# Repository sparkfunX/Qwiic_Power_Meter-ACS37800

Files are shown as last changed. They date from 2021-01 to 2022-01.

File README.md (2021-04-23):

SparkX Power Meter - ACS37800 (Qwiic)
===================================================

SparkX ACS37800 Power Meter (Qwiic) (SPX-17873) (https://www.sparkfun.com/products/17873)

[*SparkX Power Meter - ACS37800 (Qwiic) (SPX-17873)*](https://www.sparkfun.com/products/17873)

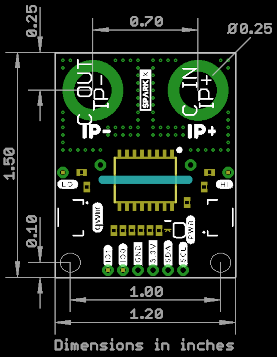
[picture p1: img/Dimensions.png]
SparkX Power Meter - ACS37800


Need a power sensor that can sense voltage up to 60VDC and current up to 30A? This is the product for you!

The Allegro MicroSystems ACS37800 power monitoring IC greatly simplifies the addition of power monitoring to many powered systems and is ideal for
heavy current applications like:
- Monitoring the power drawn by a 3D-printer
- Monitoring the power drawn from a UAV battery
- Battery charging / conditioning
- Solar / photovoltaic panel power monitoring

Allegro’s Hall-effect-based, galvanically isolated current sensing technology achieves reinforced isolation ratings in a small PCB footprint.
These features enable isolated current sensing without expensive Rogowski coils, oversized current transformers, isolated operational amplifiers,
or the power loss of shunt resistors.

The ACS37800 power monitoring IC offers key power measurement parameters that can easily be accessed through its digital interface. Dedicated and
configurable I/O pins for voltage/current zero crossing, undervoltage and overvoltage reporting, and fast overcurrent fault detection are available.
User configuration of the IC is available through on-chip EEPROM.

Important Note
-------------------
This product is not suitable for low current applications due to the +/-0.1A RMS Noise on the current channel.

Sensing less than an Amp? This is _not_ the product for you...

Safety Information
-------------------
**Although the ACS37800 power monitoring IC is capable of monitoring AC power at high line voltages, the SparkX Power Meter is designed for
Safety Extra Low Voltage (SELV) applications of up to 60VDC only. Its use in AC power systems is _not_ recommended.**

Repository Contents
-------------------
* **/Documents** - datasheets etc.
* **/Hardware** - Eagle design files (.brd, .sch)
* **/Production_Test** - production test code (.ino) - run this in the Arduino IDE
* **LICENSE.md** - license information

Documentation
--------------
* **[ACS37800 Arduino Library](https://github.com/sparkfun/SparkFun_ACS37800_Power_Monitor_Arduino_Library)** - Arduino library for the SparkFun Power Meter - ACS37800.
* **[DRAFT Hookup Guide](./HOOKUP.md)** - Basic hookup guide for the SparkX Power Meter - ACS37800.

Product Versions
----------------
* [SPX-17873](https://www.sparkfun.com/products/17873) - Original SparkX Release.

License Information
-------------------

This product is _**open source**_!

Please review the LICENSE.md file for license information.

If you have any questions or concerns on licensing, please contact technical support on our [SparkFun forums](https://forum.sparkfun.com/viewforum.php?f=123).

Distributed as-is; no warranty is given.

- Your friends at SparkFun.

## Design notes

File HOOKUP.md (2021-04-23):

# SparkX Power Meter - ACS37800 (Qwiic)

# Hook-Up Guide - DRAFT

SparkX ACS37800 Power Meter (Qwiic) (SPX-17873) (https://www.sparkfun.com/products/17873)

[*SparkX Power Meter - ACS37800 (Qwiic) (SPX-17873)*](https://www.sparkfun.com/products/17873)

Need a power sensor that can sense voltage up to 60VDC and current up to 30A? This is the product for you!

## Introduction

The Allegro MicroSystems ACS37800 power monitoring IC greatly simplifies the addition of power monitoring to many powered systems and is ideal for heavy current applications like:
- Monitoring the power drawn by a 3D-printer
- Monitoring the power drawn from a UAV battery
- Battery charging / conditioning
- Solar / photovoltaic panel power monitoring

Allegro’s Hall-effect-based, galvanically isolated current sensing technology achieves reinforced isolation ratings in a small PCB footprint. These features enable isolated current sensing without expensive Rogowski coils, oversized current transformers, isolated operational amplifiers, or the power loss of shunt resistors. The 0.85 mΩ primary conductor resistance minimises power loss and voltage drop.

The ACS37800 power monitoring IC offers key power measurement parameters that can easily be accessed through its digital interface. Dedicated and configurable I/O pins for voltage/current zero crossing, undervoltage and overvoltage reporting, and fast overcurrent fault detection are available. User configuration of the IC - including its I<sup>2</sup>C address - is available through on-chip EEPROM.

Our [Arduino library](https://github.com/sparkfun/SparkFun_ACS37800_Power_Monitor_Arduino_Library) makes it simple to add the ACS37800 into your project. We’ve also written a configuration example which you can use to examine and change all of the ACS37800’s settings through the IDE Serial Monitor or a terminal emulator.

**_Important Note:_ This product is not suitable for low current applications due to the +/-0.1A RMS Noise on the ACS37800’s current channel. Sensing less than an Amp? This is not the product for you…**

**_Safety Information:_ Although the ACS37800 power monitoring IC is capable of monitoring AC power at high line voltages, the SparkX Power Meter is designed for Safety Extra Low Voltage (SELV) applications of up to 60VDC only. Its use in AC power systems is not recommended or condoned.**

_The [SparkFun Qwiic Connect System](https://www.sparkfun.com/qwiic) is an ecosystem of I<sup>2</sup>C sensors, actuators, shields and cables that make prototyping faster and less prone to error. All Qwiic-enabled boards use a common 1mm pitch, 4-pin JST connector. This reduces the amount of required PCB space, and polarized connections mean you can’t hook it up wrong._

**_Experimental Product:_ [SparkX](https://www.sparkfun.com/sparkx) products are rapidly produced to bring you the most cutting edge technology as it becomes available. These products are tested but come with no guarantees. Live technical support is not available for SparkX products. Head on over to our [forum](https://forum.sparkfun.com/viewforum.php?f=123) for support or to ask a question.**

## High-Side Power Measurement

The Qwiic Power Meter works best in single high-side measurement applications where the ACS37800 is able to measure voltage, current and power simultaneously:
- Connect the **IP+** terminal to your voltage source
- Connect the **IP-** terminal to the load

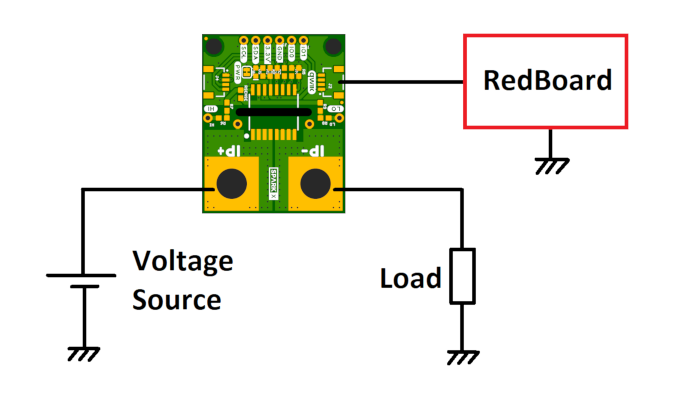
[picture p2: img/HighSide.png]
High-Side Power Measurement


In this configuration, the ACS37800 is able to measure load currents up to +/- 30 Amps. The **IP+** and **IP-** connections are electrically isolated from the rest of the circuit so, to measure voltage (and power), there needs to be a connection from the GND of the Qwiic Power Meter and RedBoard to the GND of the voltage source and load too. That connection is a low current path, only a thin wire is required, but it must be there otherwise the Qwiic Power Meter will not be able to measure voltage (and power).

Note: the RedBoard still needs to be powered in the usual way. The Qwiic Power Meter does not provide power _to_ the RedBoard.

In this example, all three Qwiic Power Meters will measure the same voltage but each will measure an individual load current and power:

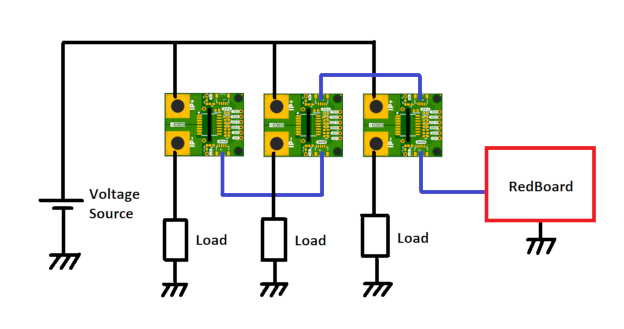
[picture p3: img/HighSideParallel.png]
High-Side Power Measurement - Parallel


The ACS37800 can be configured to use any valid I<sup>2</sup> address. The address is stored in EEPROM. Please see Example2 in the Arduino library for more details. With individual addresses, multiple Qwiic Power Meters can be daisy-chained without needing a Qwiic Mux.

In this example, all three Qwiic Power Meters will measure the same current, but different totem pole voltages (and powers):

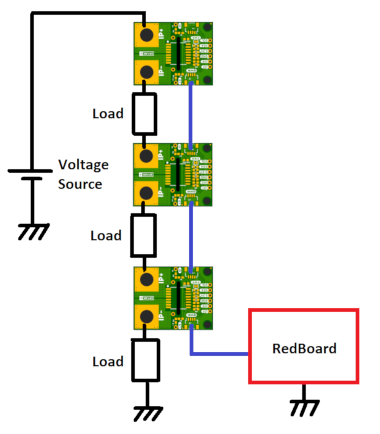
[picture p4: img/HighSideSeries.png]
High-Side Power Measurement - Series


**_Important Note:_ Be careful that the Qwiic Power Meter GND connection does not accidentally become a current path which shorts out part of the power circuit. Think very carefully before connecting a jumper wire from GND to an intermediate voltage in a multi-cell, multi-photovoltaic panel or multi-load system. Do not do this:**

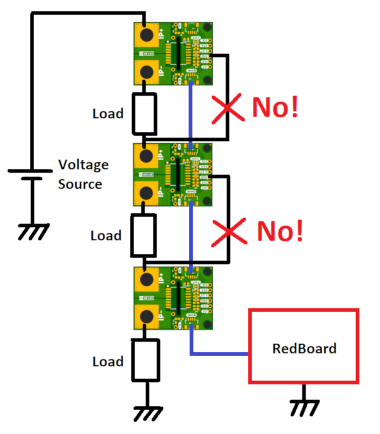
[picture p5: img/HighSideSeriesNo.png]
Do Not Do This


## Low-Side Current Measurement

The Qwiic Power Meter can be connected into the low-side of a power circuit too. However, when connected like this, it is only able to measure current, not voltage or power. (Advanced users can: cut the **IP+** split-pad jumper link on the rear of the board; and then connect the **HI** breakout pad to the high side of the load. Consult the schematic for more details.)

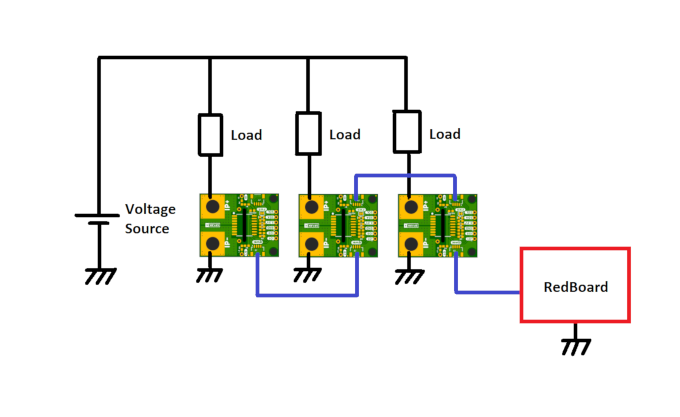
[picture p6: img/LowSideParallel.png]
Low-Side Power Measurement - Parallel


Note: the RedBoard still needs to be powered in the usual way. The Qwiic Power Meter does not provide power _to_ the RedBoard.

The ACS37800 can be configured to use any valid I<sup>2</sup> address. The address is stored in EEPROM. Please see Example2 in the Arduino library for more details. With individual addresses, multiple Qwiic Power Meters can be daisy-chained without needing a Qwiic Mux.

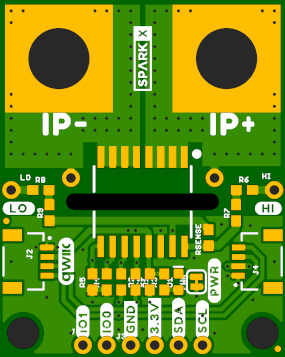
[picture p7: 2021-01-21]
img/Top.png

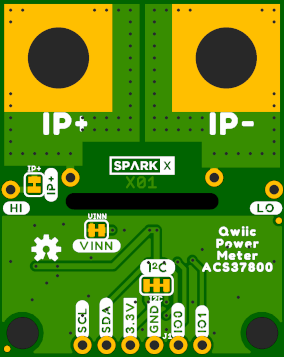
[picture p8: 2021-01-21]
img/Bottom.png

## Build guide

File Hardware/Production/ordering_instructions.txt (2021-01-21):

panel size, 138x130mm
PCB thickness, 1.6mm
number of layers, 2
soldermask color, Black
silkscreen color, White
oz copper, 2oz
finish, ENIG
stencils, top
pcs per panel, 12
min trace width, 0.4064mm / 0.0160in
min drill size, 0.3000mm / 0.0118in

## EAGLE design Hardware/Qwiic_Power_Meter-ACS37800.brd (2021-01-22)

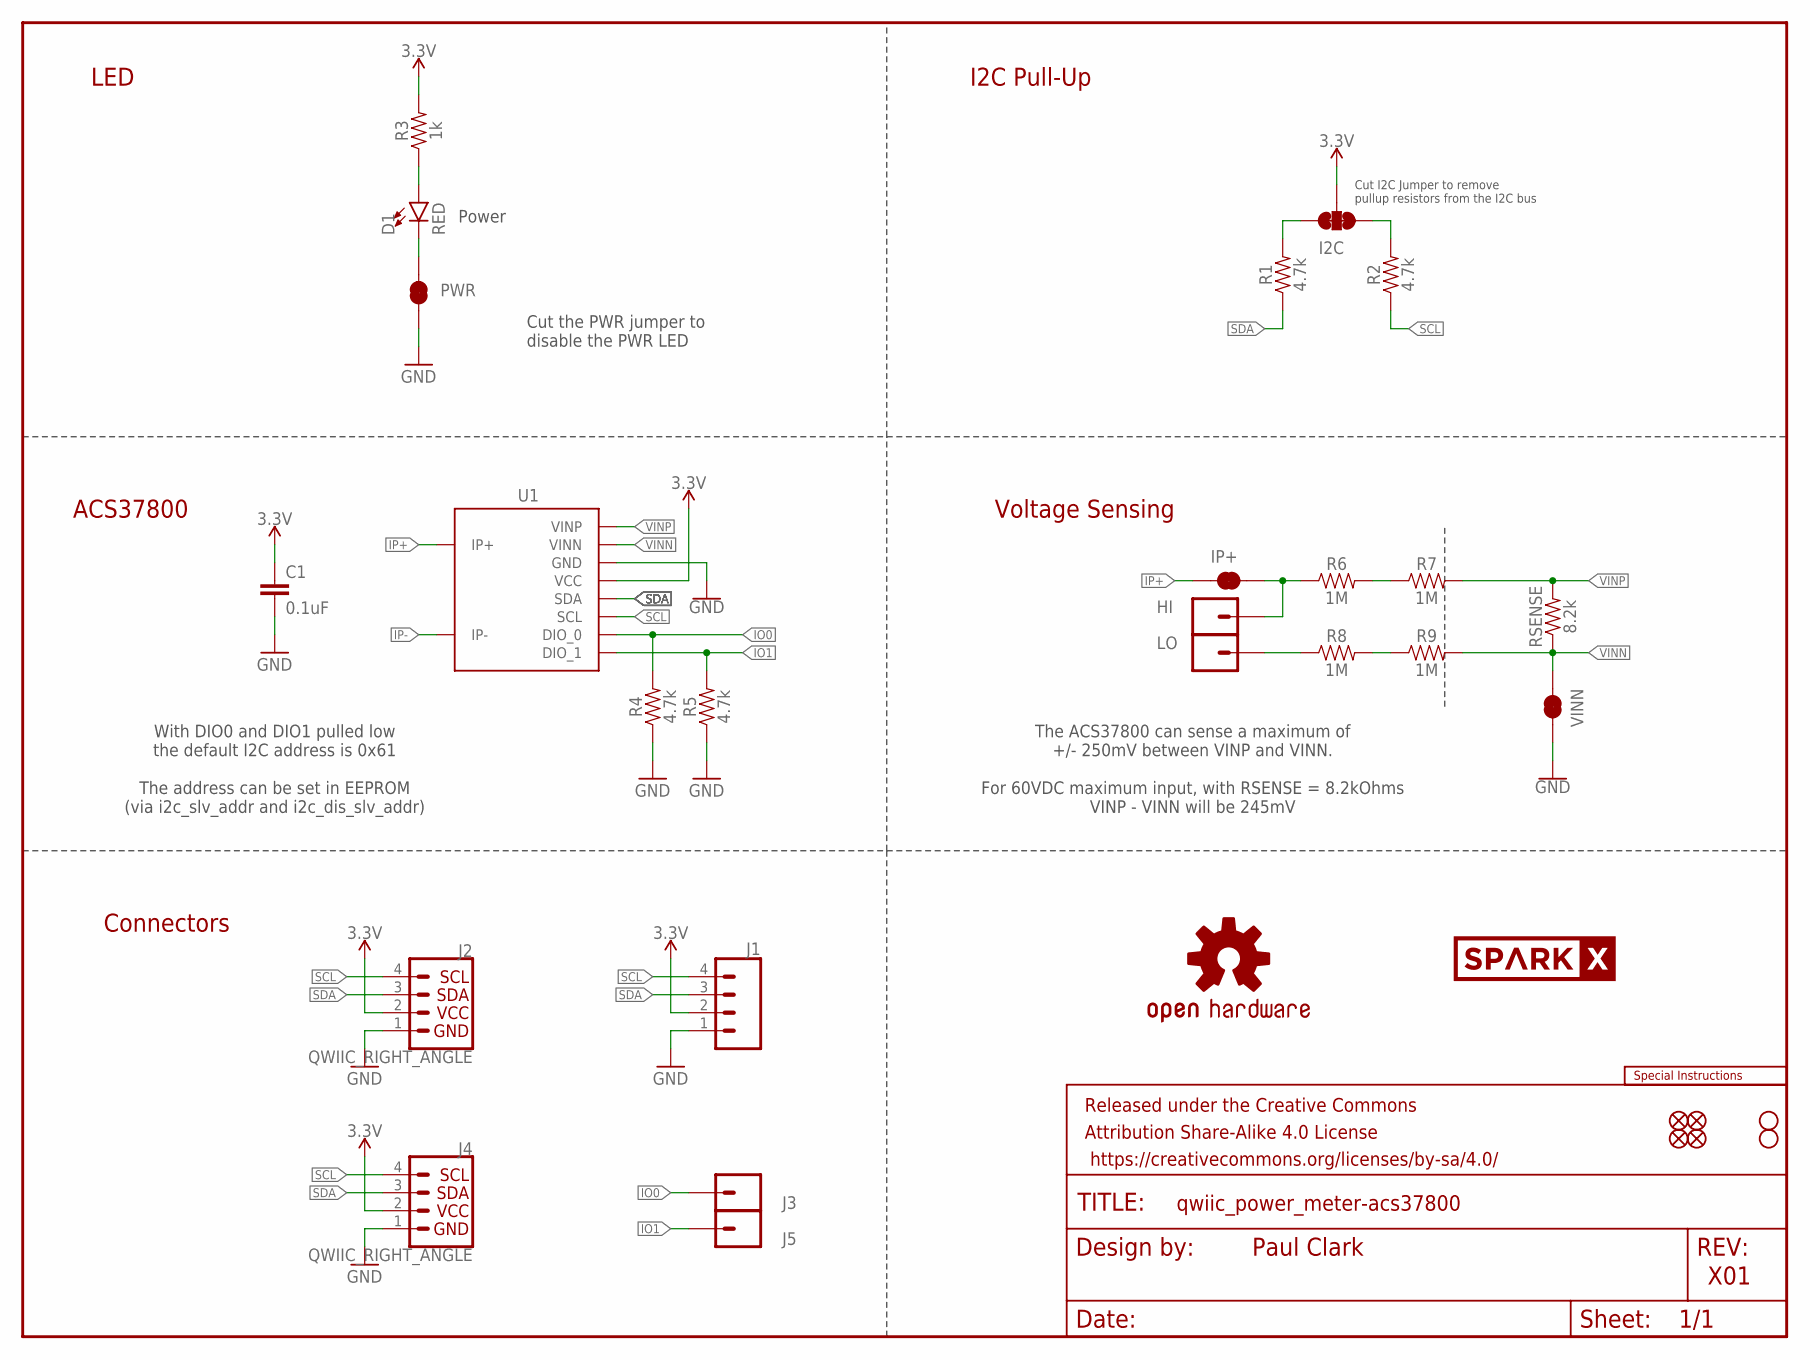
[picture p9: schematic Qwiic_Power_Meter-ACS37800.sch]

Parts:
C1: 0.1uF; 0603
D1: RED; LED-0603
FRAME1: FRAME-LETTER; CREATIVE_COMMONS
HI: CONN_01PTH_NO_SILK_YES_STOP; 1X01_NO_SILK
I2C: JUMPER-SMT_3_2-NC_TRACE_SILK; SMT-JUMPER_3_2-NC_TRACE_SILK
IP+: JUMPER-SMT_2_NC_TRACE_SILK; SMT-JUMPER_2_NC_TRACE_SILK
J1: CONN_041X04_NO_SILK; 1X04_NO_SILK
J2, J4: QWIIC_RIGHT_ANGLE; JST04_1MM_RA
J3, J5: CONN_01PTH_NO_SILK_YES_STOP; 1X01_NO_SILK
JP1, JP2, JP5, JP6: FIDUCIALUFIDUCIAL; MICRO-FIDUCIAL
JP3, JP4: STAND-OFF
LO: CONN_01PTH_NO_SILK_YES_STOP; 1X01_NO_SILK
LOGO1: SPECIAL_INSTRUCTIONS-ORDERING; ORDERING_INSTRUCTIONS
LOGO5: OSHW-LOGOS; OSHW-LOGO-S
PWR: JUMPER-SMT_2_NC_TRACE_SILK; SMT-JUMPER_2_NC_TRACE_SILK
R1, R2, R4, R5: 4.7k; 0603
R3: 1k; 0603
R6, R7, R8, R9: 1M; 0603
RSENSE: 8.2k; 0603
U1: ACS37800; ACS37800_THROUGH_HOLE
U$18: SPARKX-LOGO3; SPARKX-SMALL
VINN: JUMPER-SMT_2_NC_TRACE_SILK; SMT-JUMPER_2_NC_TRACE_SILK

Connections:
3.3V: C1.1, I2C.2, J1.2, J2.2, J4.2, R3.2, U1.13 (VCC)
GND: C1.2, J1.1, J2.1, J4.1, PWR.1, R4.1, R5.1, U1.14 (GND), VINN.2
HI: HI.1, IP+.2, R6.1
IO0: J3.1, R4.2, U1.10 (DIO_0)
IO1: J5.1, R5.2, U1.9 (DIO_1)
IP+: IP+.1, U1.1 (IP+), U1.2 (IP+), U1.3 (IP+), U1.4 (IP+), U1.CIN1 (IP+), U1.CIN2 (IP+), U1.CIN3 (IP+), U1.CIN4 (IP+), U1.CIN5 (IP+), U1.CIN6 (IP+), U1.CIN7 (IP+), U1.CIN8 (IP+), U1.CIN9 (IP+), U1.CIN10 (IP+), U1.CIN11 (IP+), U1.CIN12 (IP+), U1.CIN13 (IP+), U1.CIN14 (IP+), U1.CIN15 (IP+), U1.CIN16 (IP+), U1.CIN17 (IP+), U1.CIN18 (IP+), U1.CIN19 (IP+), U1.CIN20 (IP+), U1.CIN21 (IP+), U1.CIN22 (IP+), U1.CIN23 (IP+), U1.CIN24 (IP+), U1.CIN25 (IP+), U1.CIN26 (IP+), U1.CIN27 (IP+), U1.CIN28 (IP+), U1.CIN29 (IP+), U1.CIN30 (IP+), U1.CIN31 (IP+), U1.CIN32 (IP+), U1.CIN33 (IP+), U1.CIN34 (IP+), U1.CIN35 (IP+), U1.CIN36 (IP+), U1.C_IN (IP+), U1.C_IN_BREAKOUT (IP+)
IP-: U1.5 (IP-), U1.6 (IP-), U1.7 (IP-), U1.8 (IP-), U1.COUT1 (IP-), U1.COUT2 (IP-), U1.COUT3 (IP-), U1.COUT4 (IP-), U1.COUT5 (IP-), U1.COUT6 (IP-), U1.COUT7 (IP-), U1.COUT8 (IP-), U1.COUT9 (IP-), U1.COUT10 (IP-), U1.COUT11 (IP-), U1.COUT12 (IP-), U1.COUT13 (IP-), U1.COUT14 (IP-), U1.COUT15 (IP-), U1.COUT16 (IP-), U1.COUT17 (IP-), U1.COUT18 (IP-), U1.COUT19 (IP-), U1.COUT20 (IP-), U1.COUT21 (IP-), U1.COUT22 (IP-), U1.COUT23 (IP-), U1.COUT24 (IP-), U1.COUT25 (IP-), U1.COUT26 (IP-), U1.COUT27 (IP-), U1.COUT28 (IP-), U1.COUT29 (IP-), U1.COUT30 (IP-), U1.COUT31 (IP-), U1.COUT32 (IP-), U1.COUT33 (IP-), U1.COUT34 (IP-), U1.COUT35 (IP-), U1.COUT36 (IP-), U1.C_OUT (IP-), U1.C_OUT_BREAKOUT (IP-)
unnamed: D1.C, PWR.2
unnamed: I2C.3, R1.2
unnamed: D1.A, R3.1
unnamed: I2C.1, R2.2
unnamed: R6.2, R7.1
unnamed: R8.2, R9.1
unnamed: LO.1, R8.1
SCL: J1.4, J2.4, J4.4, R2.1, U1.11 (SCL)
SDA: J1.3, J2.3, J4.3, R1.1, U1.12 (SDA)
VINN: R9.2, RSENSE.1, U1.15 (VINN), VINN.1
VINP: R7.2, RSENSE.2, U1.16 (VINP)

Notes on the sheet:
Paul Clark
X01
Power
I2C Pull-Up
ACS37800
Connectors
Cut the PWR jumper to disable the PWR LED
Cut I2C Jumper to remove pullup resistors from the I2C bus
LED
Voltage Sensing
With DIO0 and DIO1 pulled low the default I2C address is 0x61 The address can be set in EEPROM (via i2c_slv_addr and i2c_dis_slv_addr)
The ACS37800 can sense a maximum of +/- 250mV between VINP and VINN. For 60VDC maximum input, with RSENSE = 8.2kOhms VINP - VINN will be 245mV

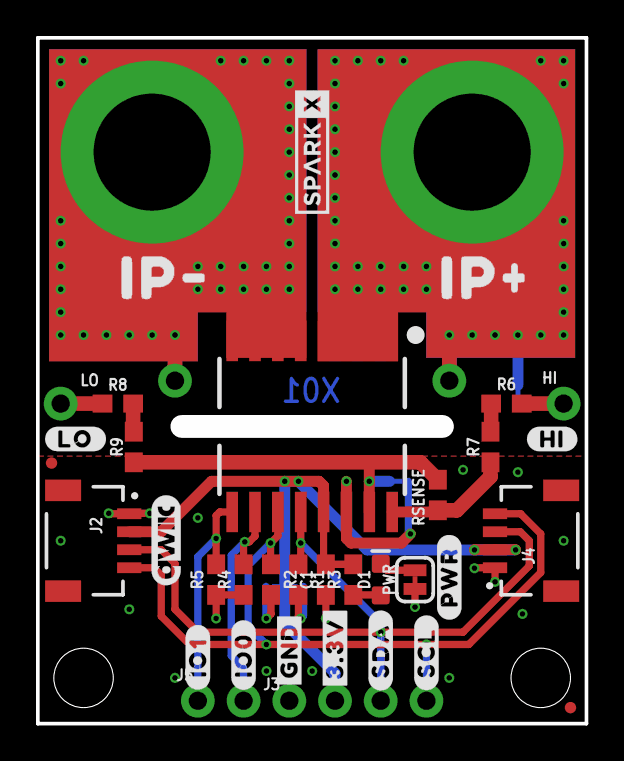
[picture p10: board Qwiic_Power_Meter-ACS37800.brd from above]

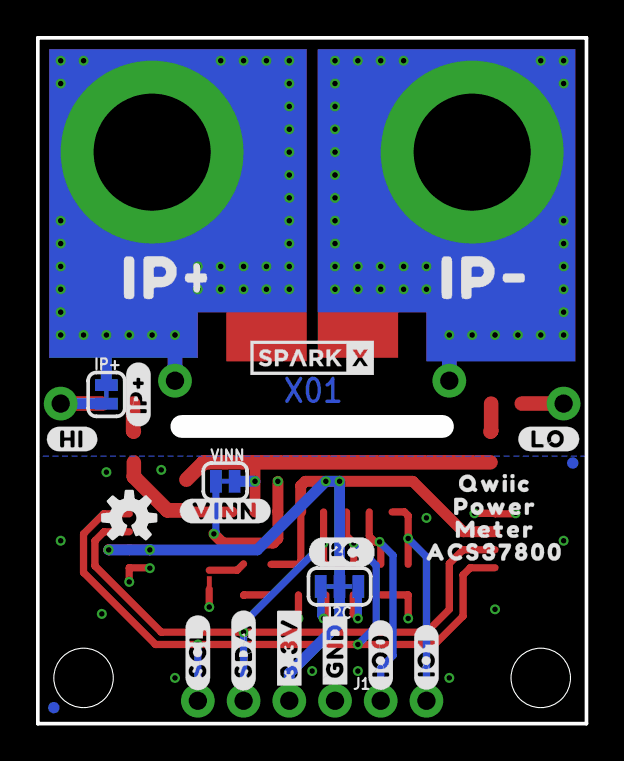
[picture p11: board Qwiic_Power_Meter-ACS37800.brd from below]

Board: 4 copper layers, 30.5 x 38.1 mm, 64 parts (25 on the bottom side), 18 nets.

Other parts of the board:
U$1, U$33: #GND#0
U$2, U$34: #3#3V#0
U$3, U$35: #SDA#0
U$4, U$36: #SCL#0
U$5, U$6: #IO0#0
U$7, U$8: #IO1#0
U$9, U$10, U$11, U$12: IP#0
U$13, U$14: #HI#0
U$15: I2C
U$16: QWIIC_5MM
U$17, U$19: #LO#0
U$20: SPARKX-LOGO3; SPARKX-SMALL
U$21: #VINN#0
U$22: #IP##0
U$23: ACS378000
U$24: METER0
U$25: POWER0
U$26: QWIIC0
U$32: #PWR#0

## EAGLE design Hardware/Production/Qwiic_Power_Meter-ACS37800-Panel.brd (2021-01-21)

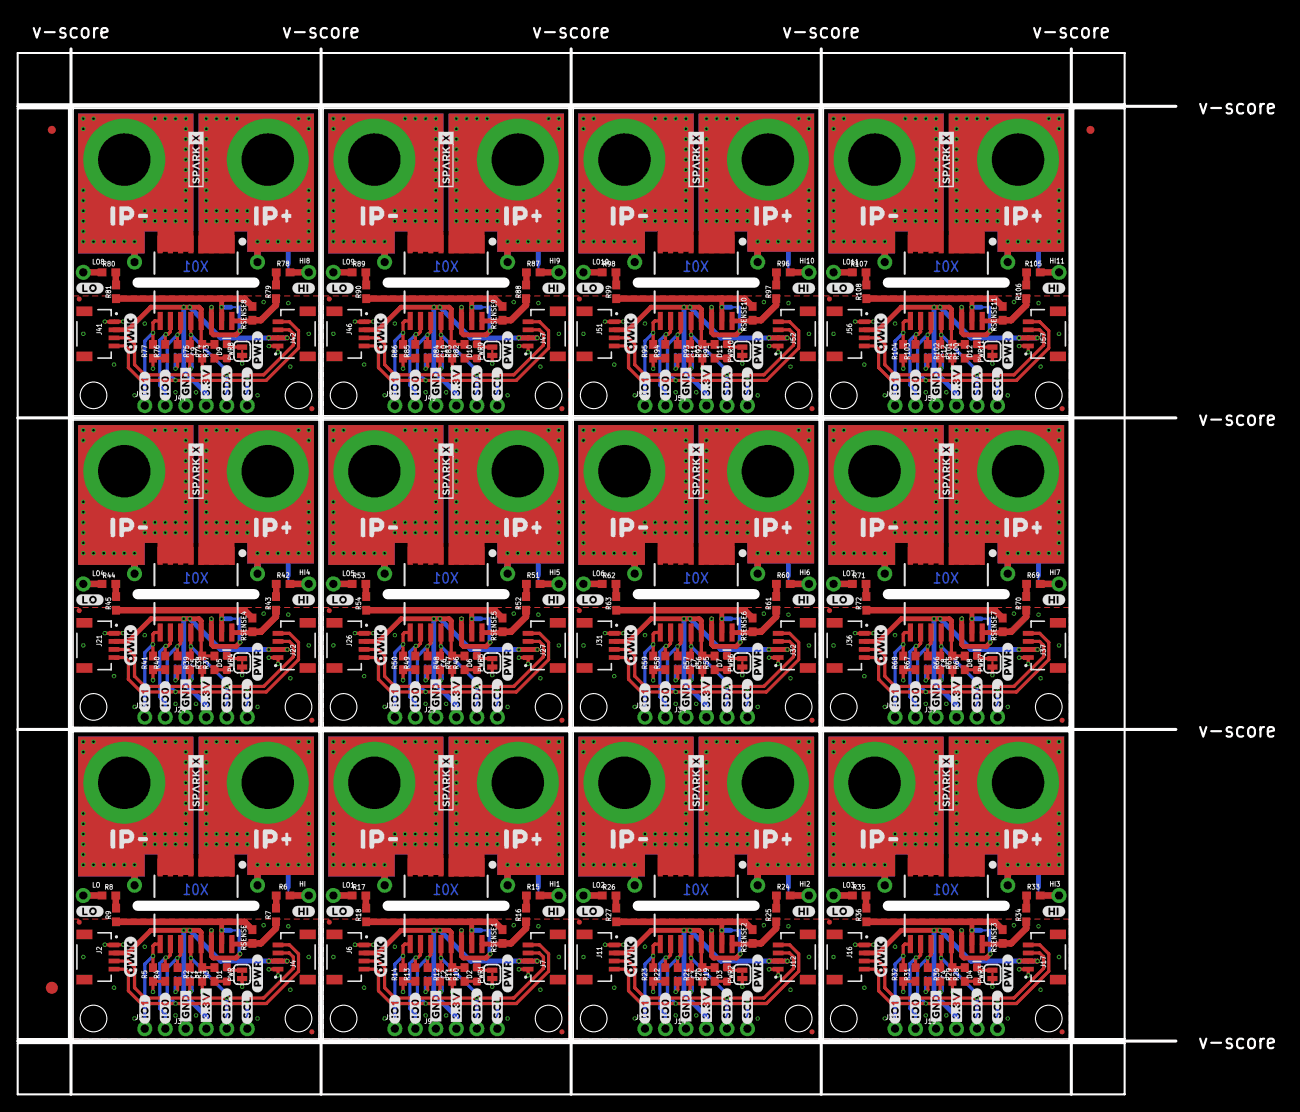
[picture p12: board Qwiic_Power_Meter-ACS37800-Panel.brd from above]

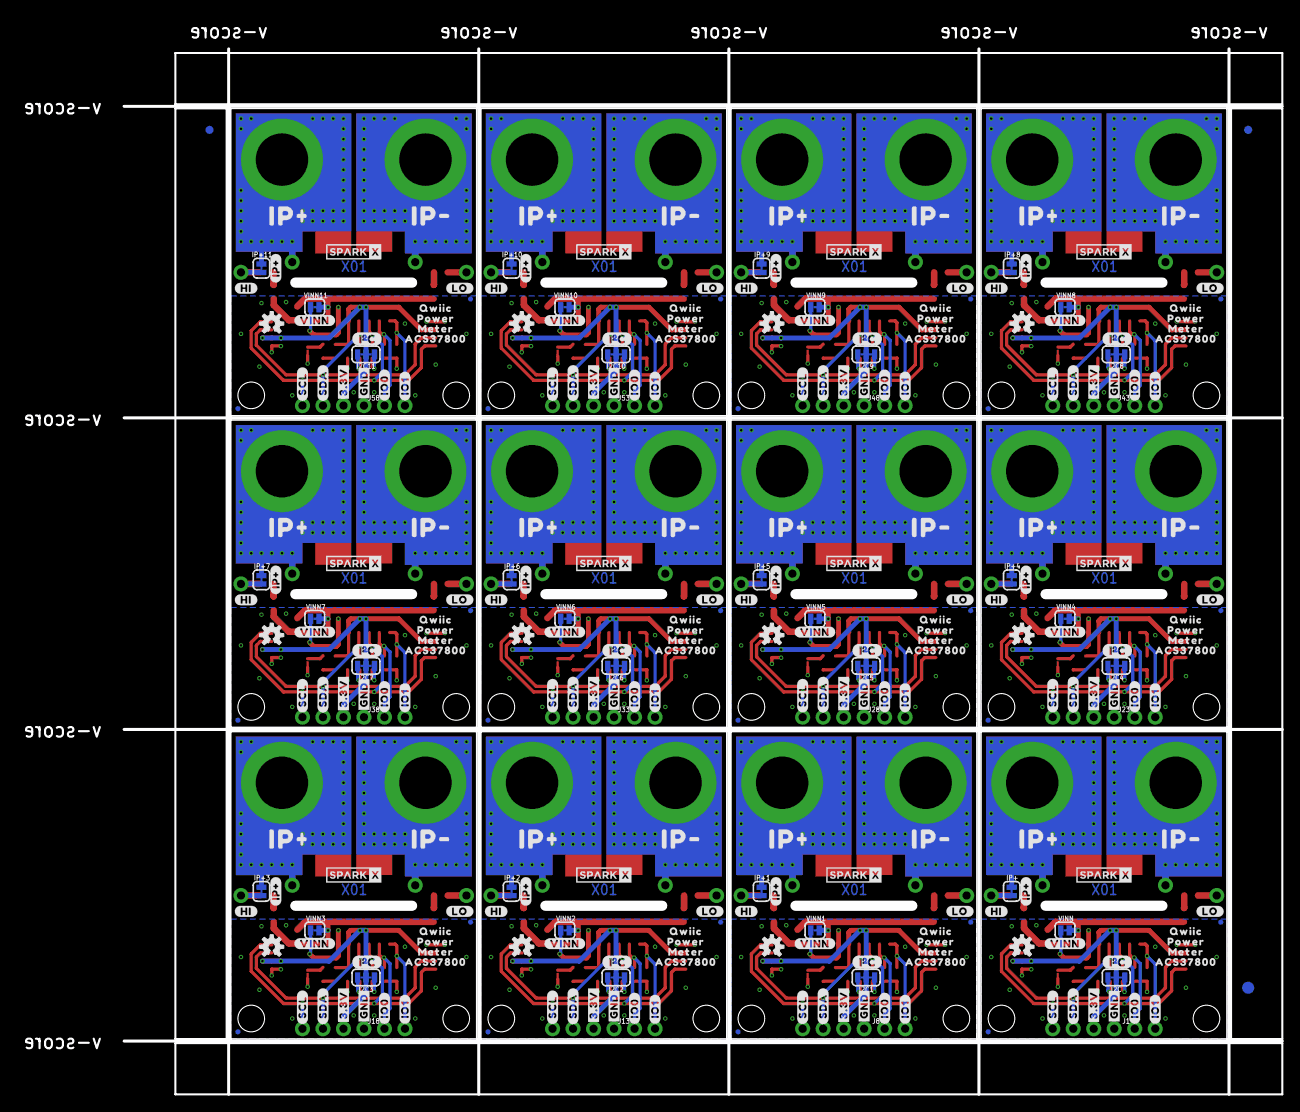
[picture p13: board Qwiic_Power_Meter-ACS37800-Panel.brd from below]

Board: 4 copper layers, 143.5 x 129.5 mm, 750 parts (303 on the bottom side), 216 nets.

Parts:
C1, C2, C3, C4, C5, C6, C7, C8, C9, C10, C11, C12: 0.1uF; 0603
D1, D2, D3, D4, D5, D6, D7, D8, D9, D10, D11, D12: RED; LED-0603
E$1, E$2, E$3, E$4: FIDUCIAL-1X2
E$5, E$6: FIDUCIAL-1.5X3
HI, HI1, HI2, HI3, HI4, HI5, HI6, HI7, HI8, HI9, HI10, HI11: 1X01_NO_SILK
I2C, I2C1, I2C2, I2C3, I2C4, I2C5, I2C6, I2C7, I2C8, I2C9, I2C10, I2C11: JUMPER-SMT_3_2-NC_TRACE_SILK; SMT-JUMPER_3_2-NC_TRACE_SILK
IP+, IP+1, IP+2, IP+3, IP+4, IP+5, IP+6, IP+7, IP+8, IP+9, IP+10, IP+11: JUMPER-SMT_2_NC_TRACE_SILK; SMT-JUMPER_2_NC_TRACE_SILK
J1, J8, J13, J18, J23, J28, J33, J38, J43, J48, J53, J58: 1X04_NO_SILK
J2, J4, J6, J7, J11, J12, J16, J17, J21, J22, J26, J27, J31, J32, J36, J37, J41, J42, J46, J47, J51, J52, J56, J57: QWIIC_RIGHT_ANGLE; JST04_1MM_RA
J3, J5, J9, J10, J14, J15, J19, J20, J24, J25, J29, J30, J34, J35, J39, J40, J44, J45, J49, J50, J54, J55, J59, J60: 1X01_NO_SILK
JP1, JP2, JP5, JP6, JP9, JP10, JP11, JP12, JP15, JP16, JP17, JP18, JP21, JP22, JP23, JP24, JP27, JP28, JP29, JP30, JP33, JP34, JP35, JP36, JP39, JP40, JP41, JP42, JP45, JP46, JP47, JP48, JP51, JP52, JP53, JP54, JP57, JP58, JP59, JP60, JP63, JP64, JP65, JP66, JP69, JP70, JP71, JP72: FIDUCIALUFIDUCIAL; MICRO-FIDUCIAL
JP3, JP4, JP7, JP8, JP13, JP14, JP19, JP20, JP25, JP26, JP31, JP32, JP37, JP38, JP43, JP44, JP49, JP50, JP55, JP56, JP61, JP62, JP67, JP68: STAND-OFF
LO, LO1, LO2, LO3, LO4, LO5, LO6, LO7, LO8, LO9, LO10, LO11: 1X01_NO_SILK
LOGO1, LOGO2, LOGO3, LOGO4, LOGO5, LOGO6, LOGO7, LOGO8, LOGO9, LOGO10, LOGO11, LOGO12: OSHW-LOGOS; OSHW-LOGO-S
PWR, PWR1, PWR2, PWR3, PWR4, PWR5, PWR6, PWR7, PWR8, PWR9, PWR10, PWR11: JUMPER-SMT_2_NC_TRACE_SILK; SMT-JUMPER_2_NC_TRACE_SILK
R1, R2, R4, R5, R11, R12, R13, R14, R20, R21, R22, R23, R29, R30, R31, R32, R38, R39, R40, R41, R47, R48, R49, R50, R56, R57, R58, R59, R65, R66, R67, R68, R74, R75, R76, R77, R83, R84, R85, R86, R92, R93, R94, R95, R101, R102, R103, R104: 4.7k; 0603
R3, R10, R19, R28, R37, R46, R55, R64, R73, R82, R91, R100: 1k; 0603
R6, R7, R8, R9, R15, R16, R17, R18, R24, R25, R26, R27, R33, R34, R35, R36, R42, R43, R44, R45, R51, R52, R53, R54, R60, R61, R62, R63, R69, R70, R71, R72, R78, R79, R80, R81, R87, R88, R89, R90, R96, R97, R98, R99, R105, R106, R107, R108: 1M; 0603
RSENSE, RSENSE1, RSENSE2, RSENSE3, RSENSE4, RSENSE5, RSENSE6, RSENSE7, RSENSE8, RSENSE9, RSENSE10, RSENSE11: 8.2k; 0603
U1, U2, U3, U4, U5, U6, U7, U8, U9, U10, U11, U12: ACS37800_THROUGH_HOLE
U$1, U$31, U$33, U$40, U$67, U$71, U$98, U$102, U$129, U$133, U$160, U$164, U$191, U$195, U$222, U$226, U$253, U$257, U$284, U$288, U$315, U$319, U$346, U$350: #GND#0
U$2, U$34, U$37, U$41, U$68, U$72, U$99, U$103, U$130, U$134, U$161, U$165, U$192, U$196, U$223, U$227, U$254, U$258, U$285, U$289, U$316, U$320, U$347, U$351: #3#3V#0
U$3, U$35, U$38, U$42, U$69, U$73, U$100, U$104, U$131, U$135, U$162, U$166, U$193, U$197, U$224, U$228, U$255, U$259, U$286, U$290, U$317, U$321, U$348, U$352: #SDA#0
U$4, U$36, U$39, U$43, U$70, U$74, U$101, U$105, U$132, U$136, U$163, U$167, U$194, U$198, U$225, U$229, U$256, U$260, U$287, U$291, U$318, U$322, U$349, U$353: #SCL#0
U$5, U$6, U$59, U$60, U$90, U$91, U$121, U$122, U$152, U$153, U$183, U$184, U$214, U$215, U$245, U$246, U$276, U$277, U$307, U$308, U$338, U$339, U$369, U$370: #IO0#0
U$7, U$8, U$61, U$62, U$92, U$93, U$123, U$124, U$154, U$155, U$185, U$186, U$216, U$217, U$247, U$248, U$278, U$279, U$309, U$310, U$340, U$341, U$371, U$372: #IO1#0
U$9, U$10, U$11, U$12, U$45, U$46, U$47, U$48, U$76, U$77, U$78, U$79, U$107, U$108, U$109, U$110, U$138, U$139, U$140, U$141, U$169, U$170, U$171, U$172, U$200, U$201, U$202, U$203, U$231, U$232, U$233, U$234, U$262, U$263, U$264, U$265, U$293, U$294, U$295, U$296, U$324, U$325, U$326, U$327, U$355, U$356, U$357, U$358: IP#0
U$13, U$14, U$49, U$50, U$80, U$81, U$111, U$112, U$142, U$143, U$173, U$174, U$204, U$205, U$235, U$236, U$266, U$267, U$297, U$298, U$328, U$329, U$359, U$360: #HI#0
U$15, U$27, U$63, U$94, U$125, U$156, U$187, U$218, U$249, U$280, U$311, U$342: I2C
U$16, U$28, U$64, U$95, U$126, U$157, U$188, U$219, U$250, U$281, U$312, U$343: QWIIC_5MM
U$17, U$19, U$51, U$52, U$82, U$83, U$113, U$114, U$144, U$145, U$175, U$176, U$206, U$207, U$237, U$238, U$268, U$269, U$299, U$300, U$330, U$331, U$361, U$362: #LO#0
U$18, U$20, U$29, U$44, U$65, U$75, U$96, U$106, U$127, U$137, U$158, U$168, U$189, U$199, U$220, U$230, U$251, U$261, U$282, U$292, U$313, U$323, U$344, U$354: SPARKX-LOGO3; SPARKX-SMALL
U$21, U$53, U$84, U$115, U$146, U$177, U$208, U$239, U$270, U$301, U$332, U$363: #VINN#0
U$22, U$54, U$85, U$116, U$147, U$178, U$209, U$240, U$271, U$302, U$333, U$364: #IP##0
U$23, U$55, U$86, U$117, U$148, U$179, U$210, U$241, U$272, U$303, U$334, U$365: ACS378000
U$24, U$56, U$87, U$118, U$149, U$180, U$211, U$242, U$273, U$304, U$335, U$366: METER0
U$25, U$57, U$88, U$119, U$150, U$181, U$212, U$243, U$274, U$305, U$336, U$367: POWER0
U$26, U$58, U$89, U$120, U$151, U$182, U$213, U$244, U$275, U$306, U$337, U$368: QWIIC0
U$30, U$32, U$66, U$97, U$128, U$159, U$190, U$221, U$252, U$283, U$314, U$345: #PWR#0
VINN, VINN1, VINN2, VINN3, VINN4, VINN5, VINN6, VINN7, VINN8, VINN9, VINN10, VINN11: JUMPER-SMT_2_NC_TRACE_SILK; SMT-JUMPER_2_NC_TRACE_SILK

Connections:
3.3V: C1.1, I2C.2, J1.2, J2.2, J4.2, R3.2, U1.13
3.3V1: C2.1, I2C1.2, J6.2, J7.2, J8.2, R10.2, U2.13
3.3V2: C3.1, I2C2.2, J11.2, J12.2, J13.2, R19.2, U3.13
3.3V3: C4.1, I2C3.2, J16.2, J17.2, J18.2, R28.2, U4.13
3.3V4: C5.1, I2C4.2, J21.2, J22.2, J23.2, R37.2, U5.13
3.3V5: C6.1, I2C5.2, J26.2, J27.2, J28.2, R46.2, U6.13
3.3V6: C7.1, I2C6.2, J31.2, J32.2, J33.2, R55.2, U7.13
3.3V7: C8.1, I2C7.2, J36.2, J37.2, J38.2, R64.2, U8.13
3.3V8: C9.1, I2C8.2, J41.2, J42.2, J43.2, R73.2, U9.13
3.3V9: C10.1, I2C9.2, J46.2, J47.2, J48.2, R82.2, U10.13
3.3V10: C11.1, I2C10.2, J51.2, J52.2, J53.2, R91.2, U11.13
3.3V11: C12.1, I2C11.2, J56.2, J57.2, J58.2, R100.2, U12.13
GND: C1.2, J1.1, J2.1, J4.1, PWR.1, R4.1, R5.1, U1.14, VINN.2
GND1: C2.2, J6.1, J7.1, J8.1, PWR1.1, R13.1, R14.1, U2.14, VINN1.2
GND2: C3.2, J11.1, J12.1, J13.1, PWR2.1, R22.1, R23.1, U3.14, VINN2.2
GND3: C4.2, J16.1, J17.1, J18.1, PWR3.1, R31.1, R32.1, U4.14, VINN3.2
GND4: C5.2, J21.1, J22.1, J23.1, PWR4.1, R40.1, R41.1, U5.14, VINN4.2
GND5: C6.2, J26.1, J27.1, J28.1, PWR5.1, R49.1, R50.1, U6.14, VINN5.2
GND6: C7.2, J31.1, J32.1, J33.1, PWR6.1, R58.1, R59.1, U7.14, VINN6.2
GND7: C8.2, J36.1, J37.1, J38.1, PWR7.1, R67.1, R68.1, U8.14, VINN7.2
GND8: C9.2, J41.1, J42.1, J43.1, PWR8.1, R76.1, R77.1, U9.14, VINN8.2
GND9: C10.2, J46.1, J47.1, J48.1, PWR9.1, R85.1, R86.1, U10.14, VINN9.2
GND10: C11.2, J51.1, J52.1, J53.1, PWR10.1, R94.1, R95.1, U11.14, VINN10.2
GND11: C12.2, J56.1, J57.1, J58.1, PWR11.1, R103.1, R104.1, U12.14, VINN11.2
HI: HI.1, IP+.2, R6.1
HI1: HI1.1, IP+1.2, R15.1
HI2: HI2.1, IP+2.2, R24.1
HI3: HI3.1, IP+3.2, R33.1
HI4: HI4.1, IP+4.2, R42.1
HI5: HI5.1, IP+5.2, R51.1
HI6: HI6.1, IP+6.2, R60.1
HI7: HI7.1, IP+7.2, R69.1
HI8: HI8.1, IP+8.2, R78.1
HI9: HI9.1, IP+9.2, R87.1
HI10: HI10.1, IP+10.2, R96.1
HI11: HI11.1, IP+11.2, R105.1
IO0: J3.1, R4.2, U1.10
IO1: J5.1, R5.2, U1.9
IO2: J9.1, R13.2, U2.10
IO3: J10.1, R14.2, U2.9
IO4: J14.1, R22.2, U3.10
IO5: J15.1, R23.2, U3.9
IO6: J19.1, R31.2, U4.10
IO7: J20.1, R32.2, U4.9
IO8: J24.1, R40.2, U5.10
IO9: J25.1, R41.2, U5.9
IO10: J29.1, R49.2, U6.10
IO11: J30.1, R50.2, U6.9
IO12: J34.1, R58.2, U7.10
IO13: J35.1, R59.2, U7.9
IO14: J39.1, R67.2, U8.10
IO15: J40.1, R68.2, U8.9
IO16: J44.1, R76.2, U9.10
IO17: J45.1, R77.2, U9.9
IO18: J49.1, R85.2, U10.10
IO19: J50.1, R86.2, U10.9
IO20: J54.1, R94.2, U11.10
IO21: J55.1, R95.2, U11.9
IO22: J59.1, R103.2, U12.10
IO23: J60.1, R104.2, U12.9
IP+: IP+.1, U1.1, U1.2, U1.3, U1.4, U1.CIN1, U1.CIN2, U1.CIN3, U1.CIN4, U1.CIN5, U1.CIN6, U1.CIN7, U1.CIN8, U1.CIN9, U1.CIN10, U1.CIN11, U1.CIN12, U1.CIN13, U1.CIN14, U1.CIN15, U1.CIN16, U1.CIN17, U1.CIN18, U1.CIN19, U1.CIN20, U1.CIN21, U1.CIN22, U1.CIN23, U1.CIN24, U1.CIN25, U1.CIN26, U1.CIN27, U1.CIN28, U1.CIN29, U1.CIN30, U1.CIN31, U1.CIN32, U1.CIN33, U1.CIN34, U1.CIN35, U1.CIN36, U1.C_IN, U1.C_IN_BREAKOUT
IP+1: IP+1.1, U2.1, U2.2, U2.3, U2.4, U2.CIN1, U2.CIN2, U2.CIN3, U2.CIN4, U2.CIN5, U2.CIN6, U2.CIN7, U2.CIN8, U2.CIN9, U2.CIN10, U2.CIN11, U2.CIN12, U2.CIN13, U2.CIN14, U2.CIN15, U2.CIN16, U2.CIN17, U2.CIN18, U2.CIN19, U2.CIN20, U2.CIN21, U2.CIN22, U2.CIN23, U2.CIN24, U2.CIN25, U2.CIN26, U2.CIN27, U2.CIN28, U2.CIN29, U2.CIN30, U2.CIN31, U2.CIN32, U2.CIN33, U2.CIN34, U2.CIN35, U2.CIN36, U2.C_IN, U2.C_IN_BREAKOUT
IP+2: IP+2.1, U3.1, U3.2, U3.3, U3.4, U3.CIN1, U3.CIN2, U3.CIN3, U3.CIN4, U3.CIN5, U3.CIN6, U3.CIN7, U3.CIN8, U3.CIN9, U3.CIN10, U3.CIN11, U3.CIN12, U3.CIN13, U3.CIN14, U3.CIN15, U3.CIN16, U3.CIN17, U3.CIN18, U3.CIN19, U3.CIN20, U3.CIN21, U3.CIN22, U3.CIN23, U3.CIN24, U3.CIN25, U3.CIN26, U3.CIN27, U3.CIN28, U3.CIN29, U3.CIN30, U3.CIN31, U3.CIN32, U3.CIN33, U3.CIN34, U3.CIN35, U3.CIN36, U3.C_IN, U3.C_IN_BREAKOUT
IP+3: IP+3.1, U4.1, U4.2, U4.3, U4.4, U4.CIN1, U4.CIN2, U4.CIN3, U4.CIN4, U4.CIN5, U4.CIN6, U4.CIN7, U4.CIN8, U4.CIN9, U4.CIN10, U4.CIN11, U4.CIN12, U4.CIN13, U4.CIN14, U4.CIN15, U4.CIN16, U4.CIN17, U4.CIN18, U4.CIN19, U4.CIN20, U4.CIN21, U4.CIN22, U4.CIN23, U4.CIN24, U4.CIN25, U4.CIN26, U4.CIN27, U4.CIN28, U4.CIN29, U4.CIN30, U4.CIN31, U4.CIN32, U4.CIN33, U4.CIN34, U4.CIN35, U4.CIN36, U4.C_IN, U4.C_IN_BREAKOUT
IP+4: IP+4.1, U5.1, U5.2, U5.3, U5.4, U5.CIN1, U5.CIN2, U5.CIN3, U5.CIN4, U5.CIN5, U5.CIN6, U5.CIN7, U5.CIN8, U5.CIN9, U5.CIN10, U5.CIN11, U5.CIN12, U5.CIN13, U5.CIN14, U5.CIN15, U5.CIN16, U5.CIN17, U5.CIN18, U5.CIN19, U5.CIN20, U5.CIN21, U5.CIN22, U5.CIN23, U5.CIN24, U5.CIN25, U5.CIN26, U5.CIN27, U5.CIN28, U5.CIN29, U5.CIN30, U5.CIN31, U5.CIN32, U5.CIN33, U5.CIN34, U5.CIN35, U5.CIN36, U5.C_IN, U5.C_IN_BREAKOUT
IP+5: IP+5.1, U6.1, U6.2, U6.3, U6.4, U6.CIN1, U6.CIN2, U6.CIN3, U6.CIN4, U6.CIN5, U6.CIN6, U6.CIN7, U6.CIN8, U6.CIN9, U6.CIN10, U6.CIN11, U6.CIN12, U6.CIN13, U6.CIN14, U6.CIN15, U6.CIN16, U6.CIN17, U6.CIN18, U6.CIN19, U6.CIN20, U6.CIN21, U6.CIN22, U6.CIN23, U6.CIN24, U6.CIN25, U6.CIN26, U6.CIN27, U6.CIN28, U6.CIN29, U6.CIN30, U6.CIN31, U6.CIN32, U6.CIN33, U6.CIN34, U6.CIN35, U6.CIN36, U6.C_IN, U6.C_IN_BREAKOUT
IP+6: IP+6.1, U7.1, U7.2, U7.3, U7.4, U7.CIN1, U7.CIN2, U7.CIN3, U7.CIN4, U7.CIN5, U7.CIN6, U7.CIN7, U7.CIN8, U7.CIN9, U7.CIN10, U7.CIN11, U7.CIN12, U7.CIN13, U7.CIN14, U7.CIN15, U7.CIN16, U7.CIN17, U7.CIN18, U7.CIN19, U7.CIN20, U7.CIN21, U7.CIN22, U7.CIN23, U7.CIN24, U7.CIN25, U7.CIN26, U7.CIN27, U7.CIN28, U7.CIN29, U7.CIN30, U7.CIN31, U7.CIN32, U7.CIN33, U7.CIN34, U7.CIN35, U7.CIN36, U7.C_IN, U7.C_IN_BREAKOUT
IP+7: IP+7.1, U8.1, U8.2, U8.3, U8.4, U8.CIN1, U8.CIN2, U8.CIN3, U8.CIN4, U8.CIN5, U8.CIN6, U8.CIN7, U8.CIN8, U8.CIN9, U8.CIN10, U8.CIN11, U8.CIN12, U8.CIN13, U8.CIN14, U8.CIN15, U8.CIN16, U8.CIN17, U8.CIN18, U8.CIN19, U8.CIN20, U8.CIN21, U8.CIN22, U8.CIN23, U8.CIN24, U8.CIN25, U8.CIN26, U8.CIN27, U8.CIN28, U8.CIN29, U8.CIN30, U8.CIN31, U8.CIN32, U8.CIN33, U8.CIN34, U8.CIN35, U8.CIN36, U8.C_IN, U8.C_IN_BREAKOUT
IP+8: IP+8.1, U9.1, U9.2, U9.3, U9.4, U9.CIN1, U9.CIN2, U9.CIN3, U9.CIN4, U9.CIN5, U9.CIN6, U9.CIN7, U9.CIN8, U9.CIN9, U9.CIN10, U9.CIN11, U9.CIN12, U9.CIN13, U9.CIN14, U9.CIN15, U9.CIN16, U9.CIN17, U9.CIN18, U9.CIN19, U9.CIN20, U9.CIN21, U9.CIN22, U9.CIN23, U9.CIN24, U9.CIN25, U9.CIN26, U9.CIN27, U9.CIN28, U9.CIN29, U9.CIN30, U9.CIN31, U9.CIN32, U9.CIN33, U9.CIN34, U9.CIN35, U9.CIN36, U9.C_IN, U9.C_IN_BREAKOUT
IP+9: IP+9.1, U10.1, U10.2, U10.3, U10.4, U10.CIN1, U10.CIN2, U10.CIN3, U10.CIN4, U10.CIN5, U10.CIN6, U10.CIN7, U10.CIN8, U10.CIN9, U10.CIN10, U10.CIN11, U10.CIN12, U10.CIN13, U10.CIN14, U10.CIN15, U10.CIN16, U10.CIN17, U10.CIN18, U10.CIN19, U10.CIN20, U10.CIN21, U10.CIN22, U10.CIN23, U10.CIN24, U10.CIN25, U10.CIN26, U10.CIN27, U10.CIN28, U10.CIN29, U10.CIN30, U10.CIN31, U10.CIN32, U10.CIN33, U10.CIN34, U10.CIN35, U10.CIN36, U10.C_IN, U10.C_IN_BREAKOUT
IP+10: IP+10.1, U11.1, U11.2, U11.3, U11.4, U11.CIN1, U11.CIN2, U11.CIN3, U11.CIN4, U11.CIN5, U11.CIN6, U11.CIN7, U11.CIN8, U11.CIN9, U11.CIN10, U11.CIN11, U11.CIN12, U11.CIN13, U11.CIN14, U11.CIN15, U11.CIN16, U11.CIN17, U11.CIN18, U11.CIN19, U11.CIN20, U11.CIN21, U11.CIN22, U11.CIN23, U11.CIN24, U11.CIN25, U11.CIN26, U11.CIN27, U11.CIN28, U11.CIN29, U11.CIN30, U11.CIN31, U11.CIN32, U11.CIN33, U11.CIN34, U11.CIN35, U11.CIN36, U11.C_IN, U11.C_IN_BREAKOUT
IP+11: IP+11.1, U12.1, U12.2, U12.3, U12.4, U12.CIN1, U12.CIN2, U12.CIN3, U12.CIN4, U12.CIN5, U12.CIN6, U12.CIN7, U12.CIN8, U12.CIN9, U12.CIN10, U12.CIN11, U12.CIN12, U12.CIN13, U12.CIN14, U12.CIN15, U12.CIN16, U12.CIN17, U12.CIN18, U12.CIN19, U12.CIN20, U12.CIN21, U12.CIN22, U12.CIN23, U12.CIN24, U12.CIN25, U12.CIN26, U12.CIN27, U12.CIN28, U12.CIN29, U12.CIN30, U12.CIN31, U12.CIN32, U12.CIN33, U12.CIN34, U12.CIN35, U12.CIN36, U12.C_IN, U12.C_IN_BREAKOUT
IP-: U1.5, U1.6, U1.7, U1.8, U1.COUT1, U1.COUT2, U1.COUT3, U1.COUT4, U1.COUT5, U1.COUT6, U1.COUT7, U1.COUT8, U1.COUT9, U1.COUT10, U1.COUT11, U1.COUT12, U1.COUT13, U1.COUT14, U1.COUT15, U1.COUT16, U1.COUT17, U1.COUT18, U1.COUT19, U1.COUT20, U1.COUT21, U1.COUT22, U1.COUT23, U1.COUT24, U1.COUT25, U1.COUT26, U1.COUT27, U1.COUT28, U1.COUT29, U1.COUT30, U1.COUT31, U1.COUT32, U1.COUT33, U1.COUT34, U1.COUT35, U1.COUT36, U1.C_OUT, U1.C_OUT_BREAKOUT
IP-1: U2.5, U2.6, U2.7, U2.8, U2.COUT1, U2.COUT2, U2.COUT3, U2.COUT4, U2.COUT5, U2.COUT6, U2.COUT7, U2.COUT8, U2.COUT9, U2.COUT10, U2.COUT11, U2.COUT12, U2.COUT13, U2.COUT14, U2.COUT15, U2.COUT16, U2.COUT17, U2.COUT18, U2.COUT19, U2.COUT20, U2.COUT21, U2.COUT22, U2.COUT23, U2.COUT24, U2.COUT25, U2.COUT26, U2.COUT27, U2.COUT28, U2.COUT29, U2.COUT30, U2.COUT31, U2.COUT32, U2.COUT33, U2.COUT34, U2.COUT35, U2.COUT36, U2.C_OUT, U2.C_OUT_BREAKOUT
IP-2: U3.5, U3.6, U3.7, U3.8, U3.COUT1, U3.COUT2, U3.COUT3, U3.COUT4, U3.COUT5, U3.COUT6, U3.COUT7, U3.COUT8, U3.COUT9, U3.COUT10, U3.COUT11, U3.COUT12, U3.COUT13, U3.COUT14, U3.COUT15, U3.COUT16, U3.COUT17, U3.COUT18, U3.COUT19, U3.COUT20, U3.COUT21, U3.COUT22, U3.COUT23, U3.COUT24, U3.COUT25, U3.COUT26, U3.COUT27, U3.COUT28, U3.COUT29, U3.COUT30, U3.COUT31, U3.COUT32, U3.COUT33, U3.COUT34, U3.COUT35, U3.COUT36, U3.C_OUT, U3.C_OUT_BREAKOUT
IP-3: U4.5, U4.6, U4.7, U4.8, U4.COUT1, U4.COUT2, U4.COUT3, U4.COUT4, U4.COUT5, U4.COUT6, U4.COUT7, U4.COUT8, U4.COUT9, U4.COUT10, U4.COUT11, U4.COUT12, U4.COUT13, U4.COUT14, U4.COUT15, U4.COUT16, U4.COUT17, U4.COUT18, U4.COUT19, U4.COUT20, U4.COUT21, U4.COUT22, U4.COUT23, U4.COUT24, U4.COUT25, U4.COUT26, U4.COUT27, U4.COUT28, U4.COUT29, U4.COUT30, U4.COUT31, U4.COUT32, U4.COUT33, U4.COUT34, U4.COUT35, U4.COUT36, U4.C_OUT, U4.C_OUT_BREAKOUT
IP-4: U5.5, U5.6, U5.7, U5.8, U5.COUT1, U5.COUT2, U5.COUT3, U5.COUT4, U5.COUT5, U5.COUT6, U5.COUT7, U5.COUT8, U5.COUT9, U5.COUT10, U5.COUT11, U5.COUT12, U5.COUT13, U5.COUT14, U5.COUT15, U5.COUT16, U5.COUT17, U5.COUT18, U5.COUT19, U5.COUT20, U5.COUT21, U5.COUT22, U5.COUT23, U5.COUT24, U5.COUT25, U5.COUT26, U5.COUT27, U5.COUT28, U5.COUT29, U5.COUT30, U5.COUT31, U5.COUT32, U5.COUT33, U5.COUT34, U5.COUT35, U5.COUT36, U5.C_OUT, U5.C_OUT_BREAKOUT
IP-5: U6.5, U6.6, U6.7, U6.8, U6.COUT1, U6.COUT2, U6.COUT3, U6.COUT4, U6.COUT5, U6.COUT6, U6.COUT7, U6.COUT8, U6.COUT9, U6.COUT10, U6.COUT11, U6.COUT12, U6.COUT13, U6.COUT14, U6.COUT15, U6.COUT16, U6.COUT17, U6.COUT18, U6.COUT19, U6.COUT20, U6.COUT21, U6.COUT22, U6.COUT23, U6.COUT24, U6.COUT25, U6.COUT26, U6.COUT27, U6.COUT28, U6.COUT29, U6.COUT30, U6.COUT31, U6.COUT32, U6.COUT33, U6.COUT34, U6.COUT35, U6.COUT36, U6.C_OUT, U6.C_OUT_BREAKOUT
IP-6: U7.5, U7.6, U7.7, U7.8, U7.COUT1, U7.COUT2, U7.COUT3, U7.COUT4, U7.COUT5, U7.COUT6, U7.COUT7, U7.COUT8, U7.COUT9, U7.COUT10, U7.COUT11, U7.COUT12, U7.COUT13, U7.COUT14, U7.COUT15, U7.COUT16, U7.COUT17, U7.COUT18, U7.COUT19, U7.COUT20, U7.COUT21, U7.COUT22, U7.COUT23, U7.COUT24, U7.COUT25, U7.COUT26, U7.COUT27, U7.COUT28, U7.COUT29, U7.COUT30, U7.COUT31, U7.COUT32, U7.COUT33, U7.COUT34, U7.COUT35, U7.COUT36, U7.C_OUT, U7.C_OUT_BREAKOUT
IP-7: U8.5, U8.6, U8.7, U8.8, U8.COUT1, U8.COUT2, U8.COUT3, U8.COUT4, U8.COUT5, U8.COUT6, U8.COUT7, U8.COUT8, U8.COUT9, U8.COUT10, U8.COUT11, U8.COUT12, U8.COUT13, U8.COUT14, U8.COUT15, U8.COUT16, U8.COUT17, U8.COUT18, U8.COUT19, U8.COUT20, U8.COUT21, U8.COUT22, U8.COUT23, U8.COUT24, U8.COUT25, U8.COUT26, U8.COUT27, U8.COUT28, U8.COUT29, U8.COUT30, U8.COUT31, U8.COUT32, U8.COUT33, U8.COUT34, U8.COUT35, U8.COUT36, U8.C_OUT, U8.C_OUT_BREAKOUT
IP-8: U9.5, U9.6, U9.7, U9.8, U9.COUT1, U9.COUT2, U9.COUT3, U9.COUT4, U9.COUT5, U9.COUT6, U9.COUT7, U9.COUT8, U9.COUT9, U9.COUT10, U9.COUT11, U9.COUT12, U9.COUT13, U9.COUT14, U9.COUT15, U9.COUT16, U9.COUT17, U9.COUT18, U9.COUT19, U9.COUT20, U9.COUT21, U9.COUT22, U9.COUT23, U9.COUT24, U9.COUT25, U9.COUT26, U9.COUT27, U9.COUT28, U9.COUT29, U9.COUT30, U9.COUT31, U9.COUT32, U9.COUT33, U9.COUT34, U9.COUT35, U9.COUT36, U9.C_OUT, U9.C_OUT_BREAKOUT
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

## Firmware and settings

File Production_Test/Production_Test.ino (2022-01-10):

/*
  Production Test code for the Qwiic Power Meter ACS37800
  By: Paul Clark
  SparkFun Electronics
  Date: March 19th, 2021
  License: please see LICENSE.md for details

  Feel like supporting our work? Buy a board from SparkFun!
  https://www.sparkfun.com/products/17873

  LED_BUILTIN will light up if the ACS37800 is detected and the registers read correctly

*/

#include "SparkFun_ACS37800_Arduino_Library.h" // Click here to get the library: http://librarymanager/All#SparkFun_ACS37800
#include <Wire.h>

ACS37800 mySensor; //Create an object of the ACS37800 class

// Global copies of the register contents
// EEPROM registers are 0B-0F. Shadow registers are 1B-1F. Volatile registers are 20-30.
ACS37800_REGISTER_0B_t reg1B;
ACS37800_REGISTER_0D_t reg1D;

void setup()
{
  Serial.begin(115200);
  Serial.println(F("ACS37800 Production Test"));

  pinMode(LED_BUILTIN, OUTPUT);
  digitalWrite(LED_BUILTIN, LOW);
}

void loop()
{
  delay(250); // Try every 0.25 seconds

  Wire.begin();

  Wire.beginTransmission(0x60); // Detect ACS37800 on address 0x60
  if (Wire.endTransmission() != 0)
  {
    digitalWrite(LED_BUILTIN, LOW);
    Wire.end();
    Serial.println(F("Error: nothing detected on address 0x60"));
    return;
  }
  
  if (mySensor.begin(0x60) == false) //Initialize sensor using I2C address 0x60
  {
    digitalWrite(LED_BUILTIN, LOW);
    Wire.end();
    Serial.println(F("Error: .begin failed"));
    return;
  }

  // Read the shadow registers
  mySensor.readRegister(&reg1B.data.all, ACS37800_REGISTER_SHADOW_1B);
  mySensor.readRegister(&reg1D.data.all, ACS37800_REGISTER_SHADOW_1D);

  // Check the register contents
  if ((reg1B.data.bits.crs_sns < 0x3) || (reg1B.data.bits.crs_sns > 0x6))
  {
    digitalWrite(LED_BUILTIN, LOW);
    Wire.end();
    Serial.println(F("Error: invalid register value (crs_sns)"));
    return;
  }

  if (reg1D.data.bits.fault != 0x46)
  {
    digitalWrite(LED_BUILTIN, LOW);
    Wire.end();
    Serial.println(F("Error: invalid register value (fault)"));
    return;
  }

  // All good!
  digitalWrite(LED_BUILTIN, HIGH);
  Wire.end();
  Serial.println(F("ACS37800 detected! Test passed!"));
}

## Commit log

2021-01-22 Adding the SKU and new PROD_ID
    [Qwiic_Power_Meter-ACS37800.brd, Qwiic_Power_Meter-ACS37800.sch]
2021-03-15 Update default I2C address on schematic
    [Qwiic_Power_Meter-ACS37800.sch]

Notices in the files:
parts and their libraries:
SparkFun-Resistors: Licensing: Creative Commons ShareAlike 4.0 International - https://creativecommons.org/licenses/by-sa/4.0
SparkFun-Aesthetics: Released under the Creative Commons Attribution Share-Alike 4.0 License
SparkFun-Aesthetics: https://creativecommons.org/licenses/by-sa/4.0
